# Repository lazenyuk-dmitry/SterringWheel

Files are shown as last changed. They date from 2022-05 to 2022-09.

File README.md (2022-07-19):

# Самодельный игровой руль с обратной связью

Это мой проект для личного использования. Здесь только чертежи проекта. Я использовал для чертежей **[FreeCAD](https://wiki.freecadweb.org/)**, это бесплатное ПО, скачать его можно **[здесь](https://wiki.freecadweb.org/Download)**.

Я сделал руль в основном из фанеры и ЛДСП. Я использовал два мотора 775 с передаточным числом 1:10.

Электроника основана на Arduino leonardo.

Для прошивки я использовал проект **[AFFBWheel](https://github.com/vsulako/AFFBWheel)**. Автор проекта своевременно исправляет ошибки и дорабатывает прошивку, добавляет новый функционал.

*Если будет интерес к проекту то я буду дополнять описание и чертежи. О своей заинтересованности или по каким то вопросам можете писать в **[Discussions](https://github.com/lazenyuk-dmitry/SterringWheel/discussions)**.*

Цвета в проекте:

* chipboard - ЛДСП.
* plywood - фанера.

## Описание файлов проекта

* `assets` - содержит импортированные модели.
* `images` - картинки проекта.
* `pdf` - PDF файлы модели.
* `Base.FCStd` - модель базы.
* `PaddleShifter.FCStd` - модель подрулевых лепестков.
* `PaddleShifter-v2.FCStd` - подрулевые лепестки 2 версия.
* `Pedals.FCStd` - модель педалей.
* `Wheel.FCStd` - модель руля.

В программе *FreeCAD* есть справа панель. В ней ищите папку чертежи.
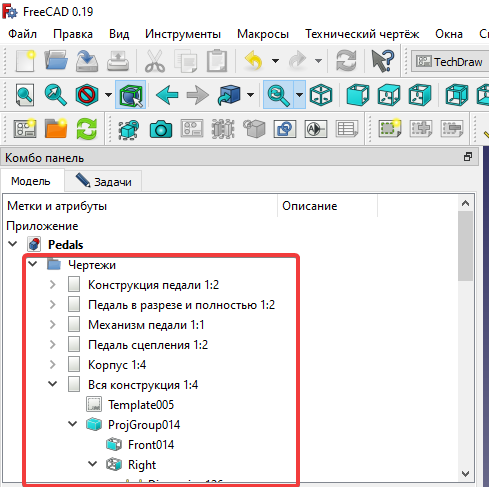
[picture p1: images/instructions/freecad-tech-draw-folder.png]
tech-draw-folder


## Немного фотографий

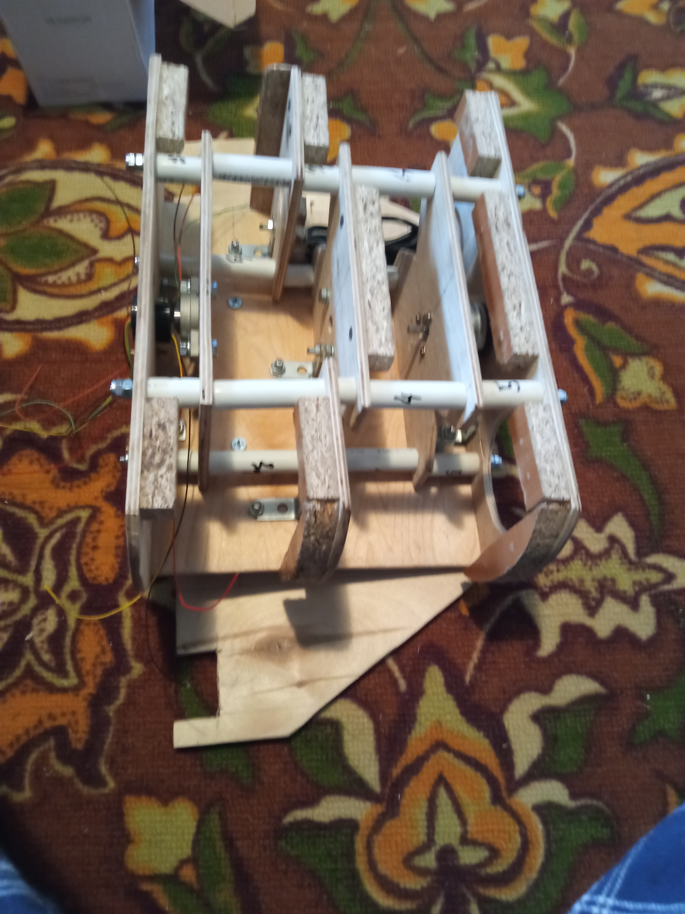
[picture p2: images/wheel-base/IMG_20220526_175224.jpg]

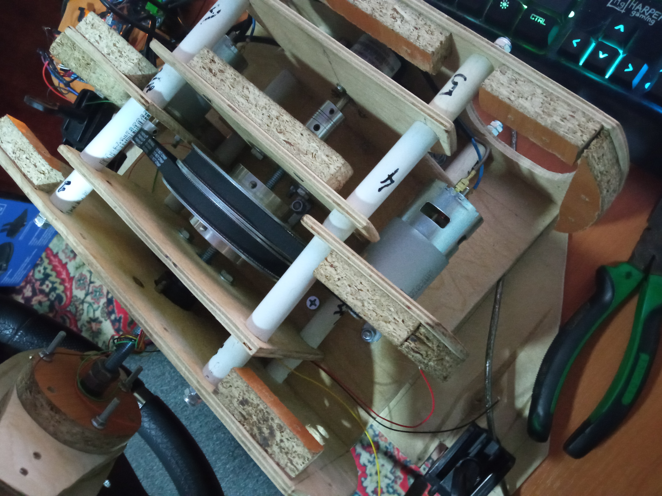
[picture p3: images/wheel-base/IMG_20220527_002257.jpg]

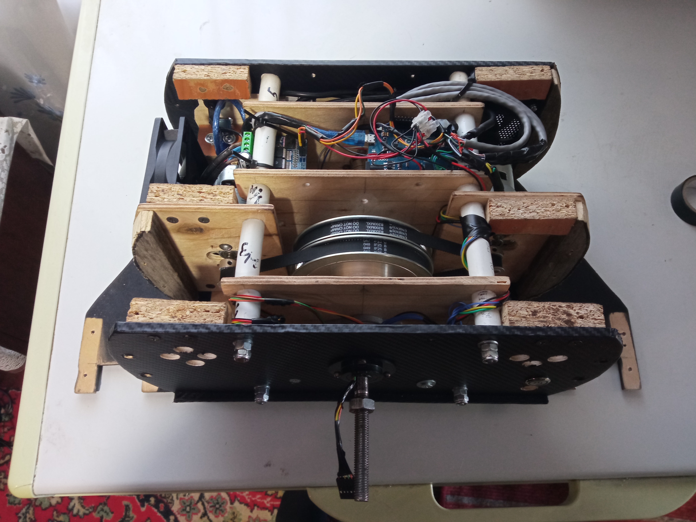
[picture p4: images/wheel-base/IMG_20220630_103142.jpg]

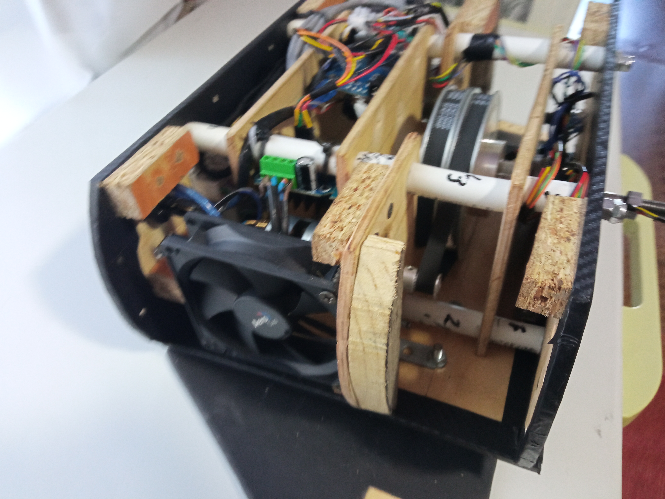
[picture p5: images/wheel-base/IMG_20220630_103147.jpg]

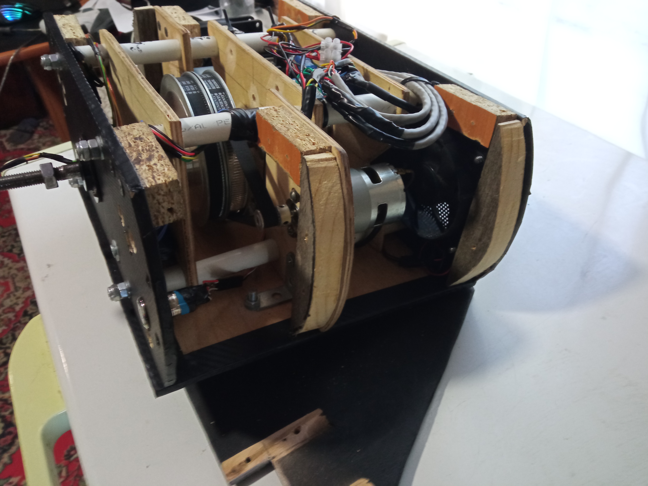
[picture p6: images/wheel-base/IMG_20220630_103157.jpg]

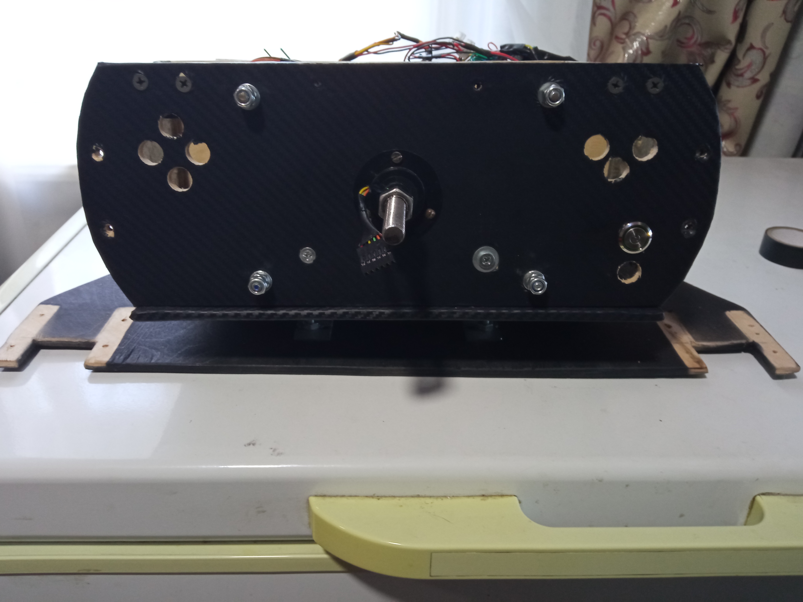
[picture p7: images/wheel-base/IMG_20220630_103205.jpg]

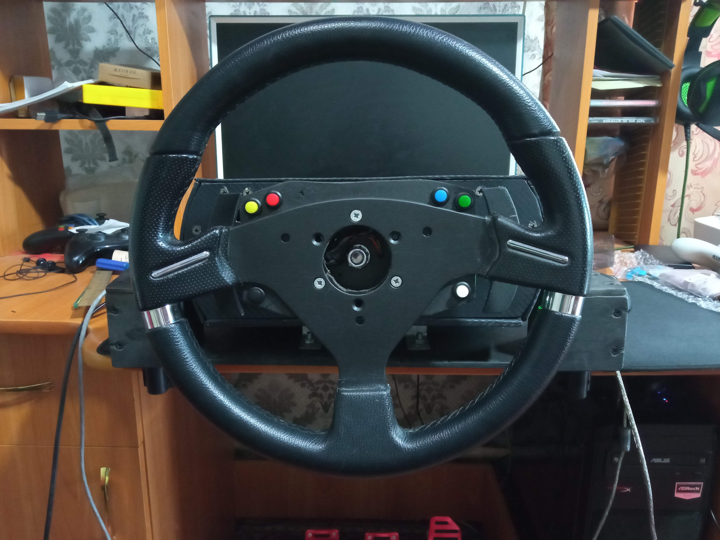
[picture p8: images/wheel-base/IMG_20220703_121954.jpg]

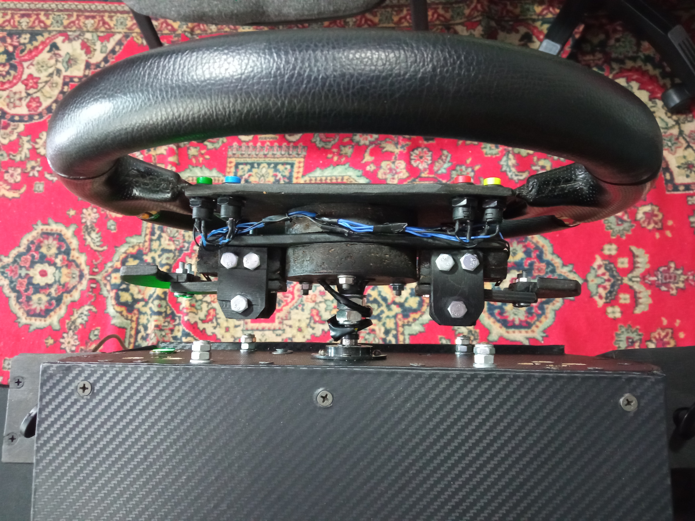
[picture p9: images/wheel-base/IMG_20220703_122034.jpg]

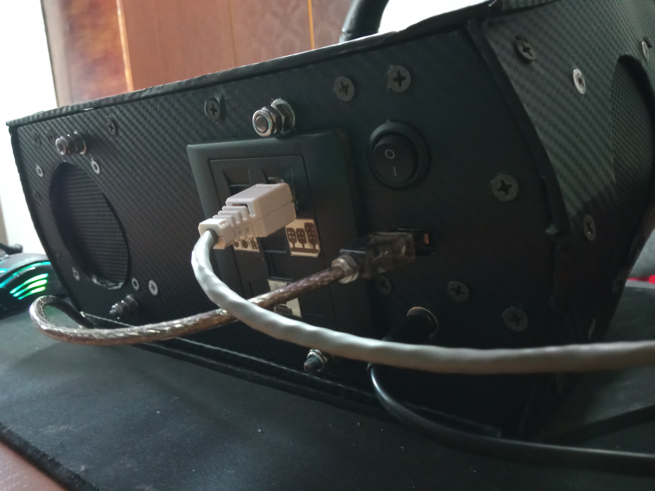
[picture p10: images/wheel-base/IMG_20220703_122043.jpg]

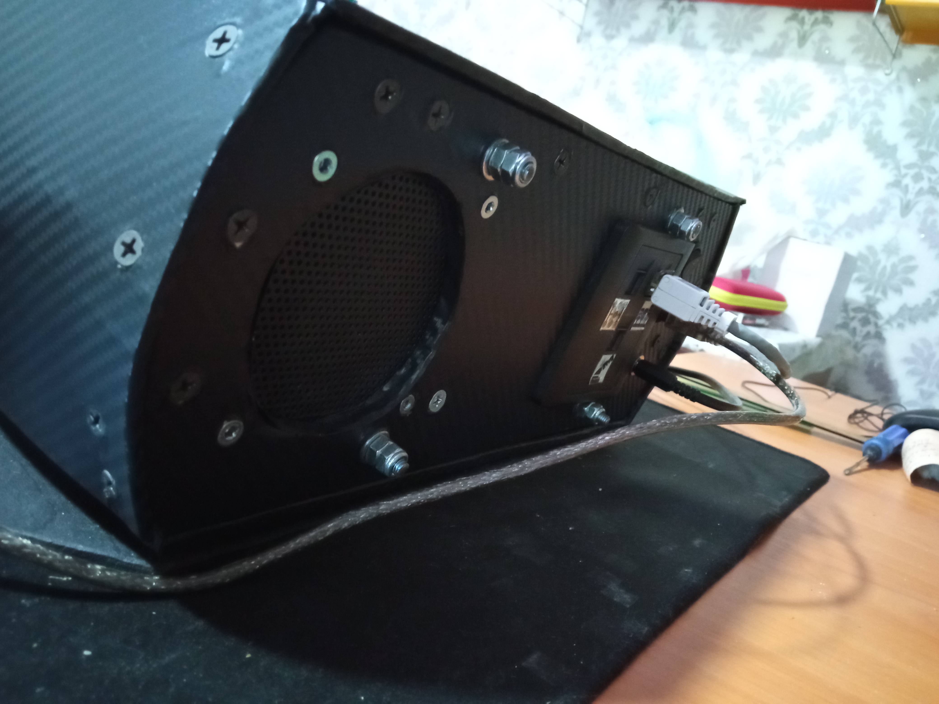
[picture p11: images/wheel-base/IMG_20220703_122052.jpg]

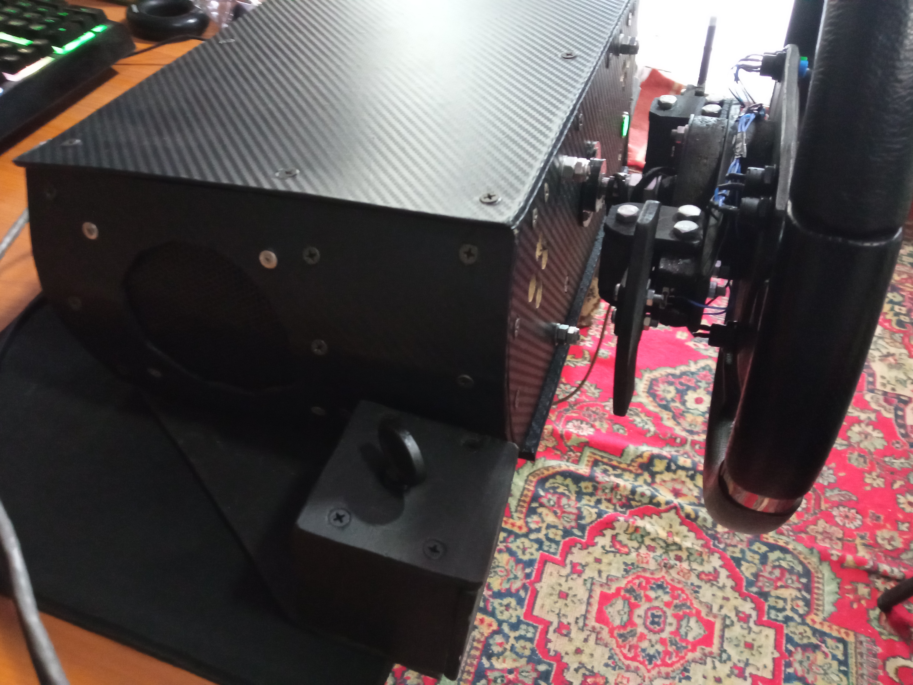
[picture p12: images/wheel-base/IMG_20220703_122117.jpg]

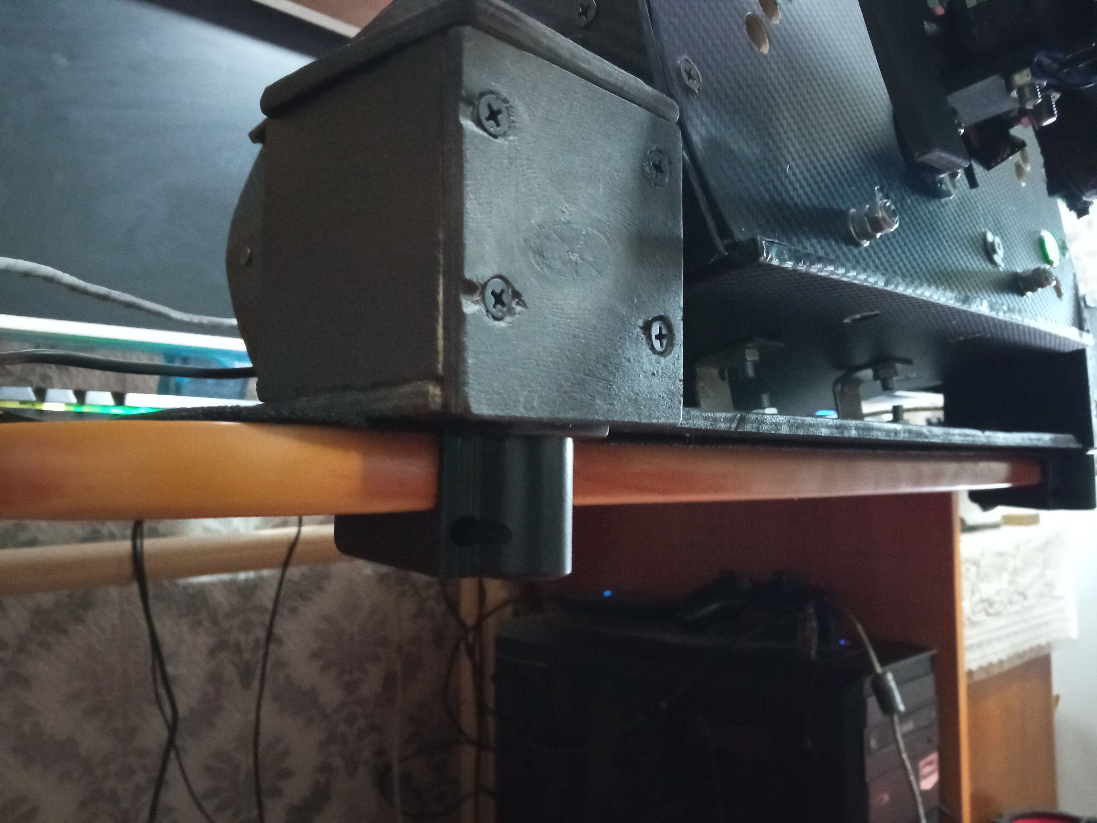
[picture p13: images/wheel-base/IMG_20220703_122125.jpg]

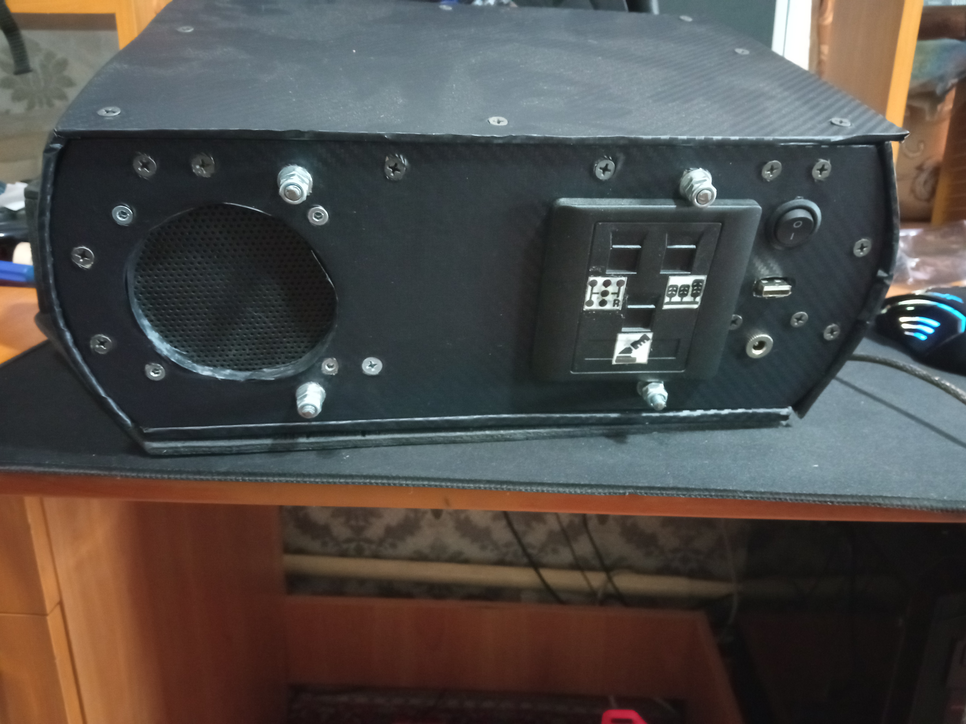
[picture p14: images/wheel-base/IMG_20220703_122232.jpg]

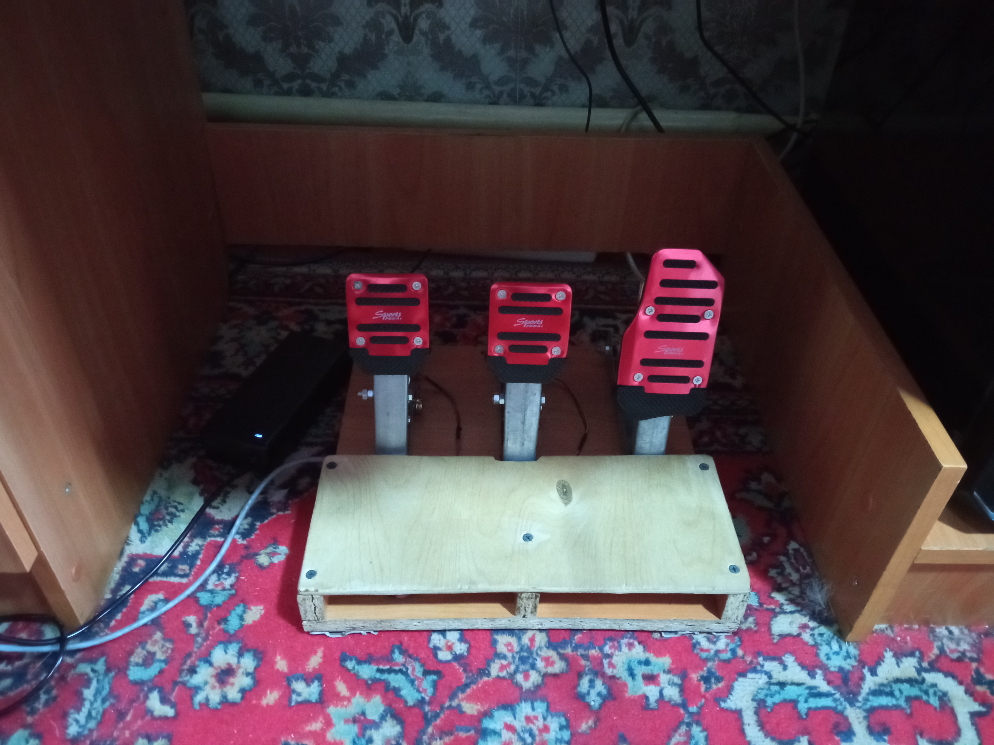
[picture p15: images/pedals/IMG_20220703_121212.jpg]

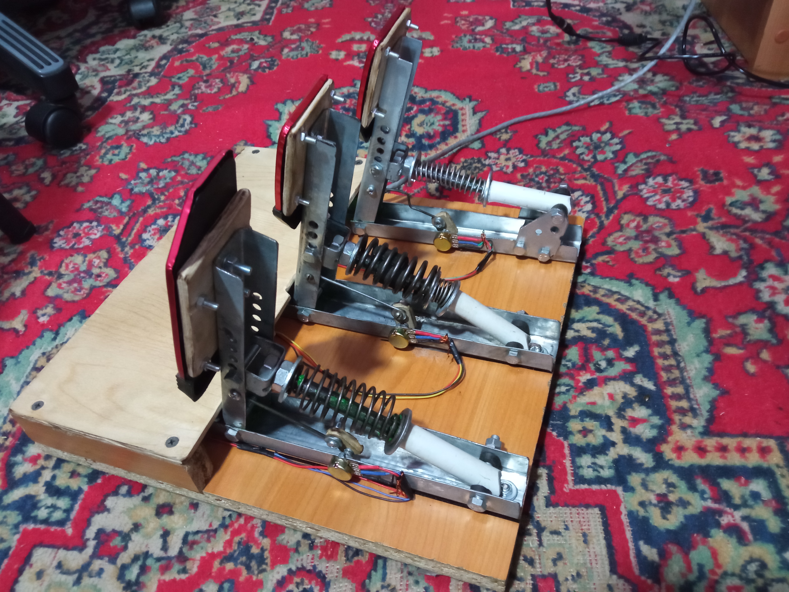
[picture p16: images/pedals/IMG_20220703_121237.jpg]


## Педали

Для педалей я использовал следующее:

* Профиль, вроде бы им усиливают пластиковые окна. Он мне достался бесплатно. <br>
 <br>
Профиль 30х20mm.
* Потенциометры на 10К.
* Проволока 1-2mm или спица от велосипеда.
* Фанера 6mm.
* ЛДСП 16mm.
* Накладки на педали я покупал **[здесь](https://aliexpress.ru/item/1005003505176644.html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)**. Но они мне не особо нравятся.
* Пружины использовал следующие:
  * Для педали газа **[Диаметр проволоки:2.0mm, Длинна:100mm (2Pcs), Наружныи диаметр:30mm](https://aliexpress.ru/item/4000436939383.html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)**. <br>
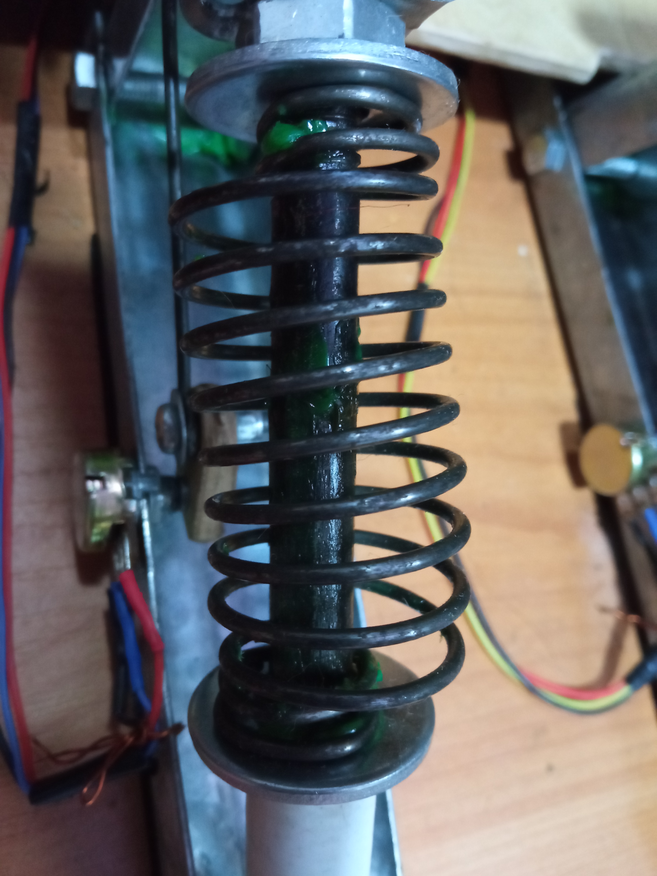
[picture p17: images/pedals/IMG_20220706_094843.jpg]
   <br>
  *Можно взять диаметр меньше так как пружина одевается на шток 10мм, возможно у вас будет другой*
  * Для педали сцепления **[1.5x18x305mm](https://aliexpress.ru/item/4001041195904.html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)**. <br>
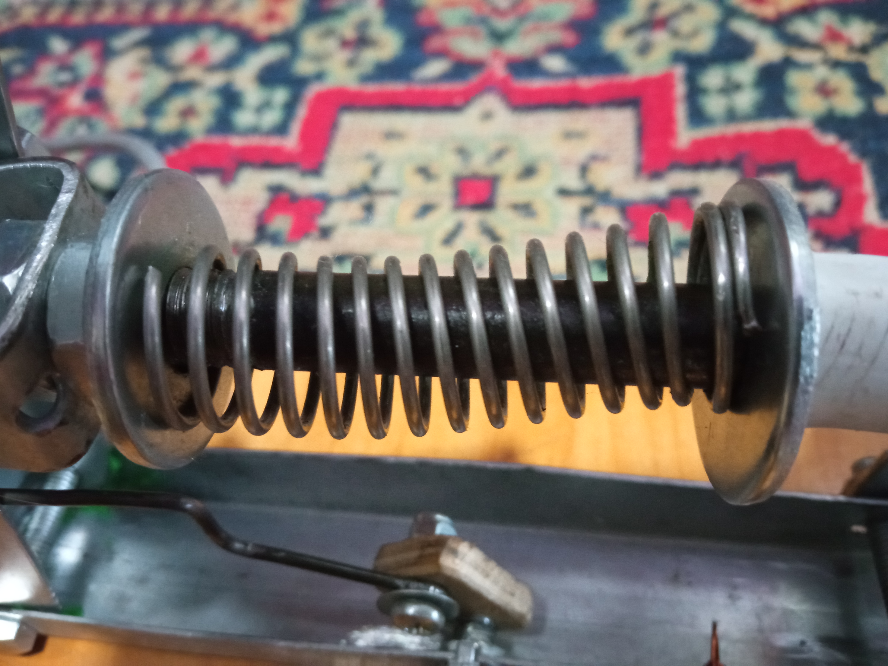
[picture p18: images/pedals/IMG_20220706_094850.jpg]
   <br>
  *Но мне кажется нужно потолще пружину ставить*.
  * На педаль тормоза я нашел пружину от клапанов *МТЗ*. Думаю можно подобрать от автомобиля или мотоцикла с клапанов. И добавил еще кусочек пружины 1.5мм <br>
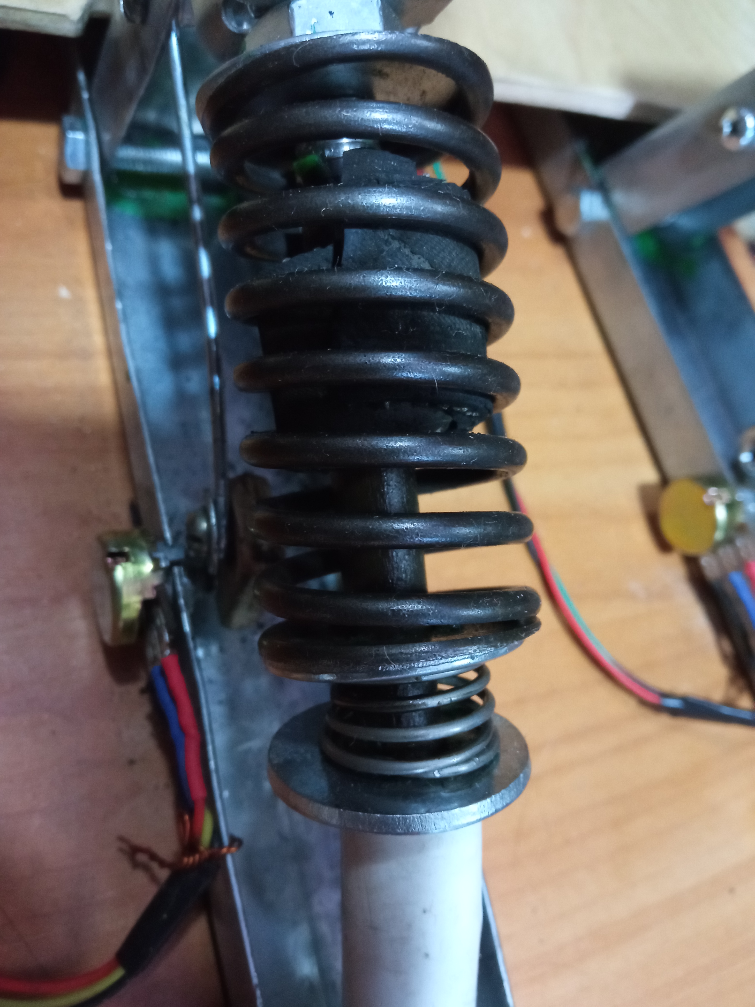
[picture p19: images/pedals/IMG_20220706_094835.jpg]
   <br>
  *У пружины большой внутренний диаметр поэтому я засунул во внутрь кусок шланга*.
* Труба металлопластик 16мм.
* Провода.
* Болты и гайки и шайбы M10, M6, M4.
* Шпилька для штока M10 а лучше прут 10мм и нарезать резьбу на краю. <br>
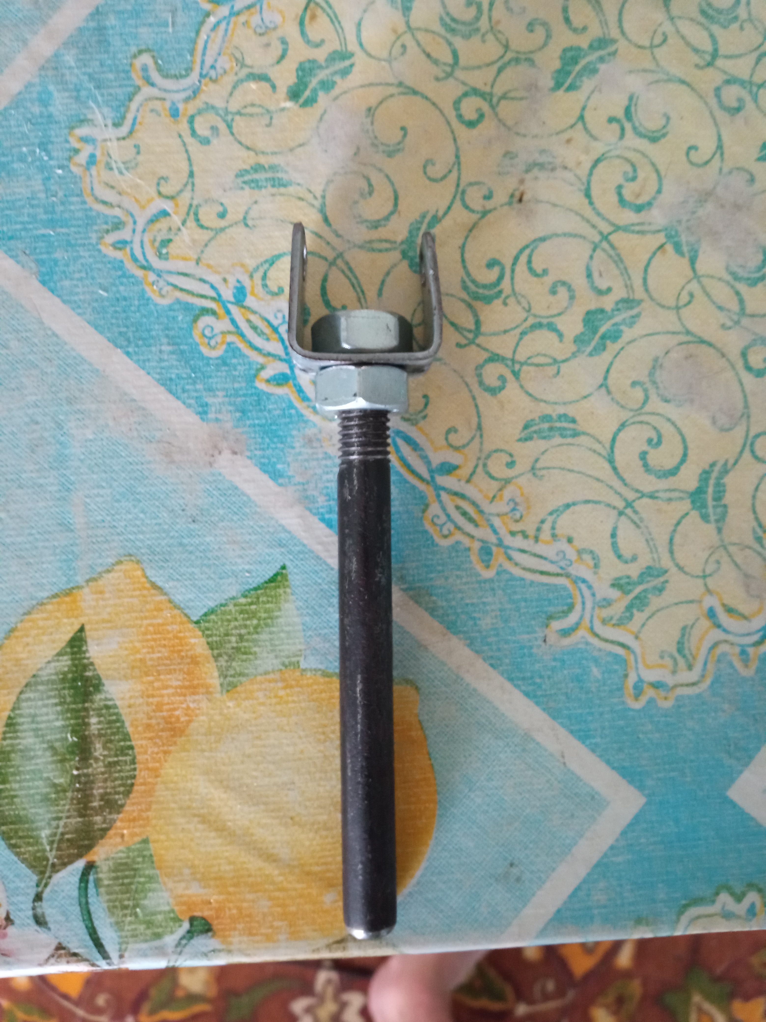
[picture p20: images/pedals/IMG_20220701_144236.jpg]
   <br>
  *Я не нашел нормальные шпильки. В магазине какая то острая резьба сильно и это мешает*. <br>
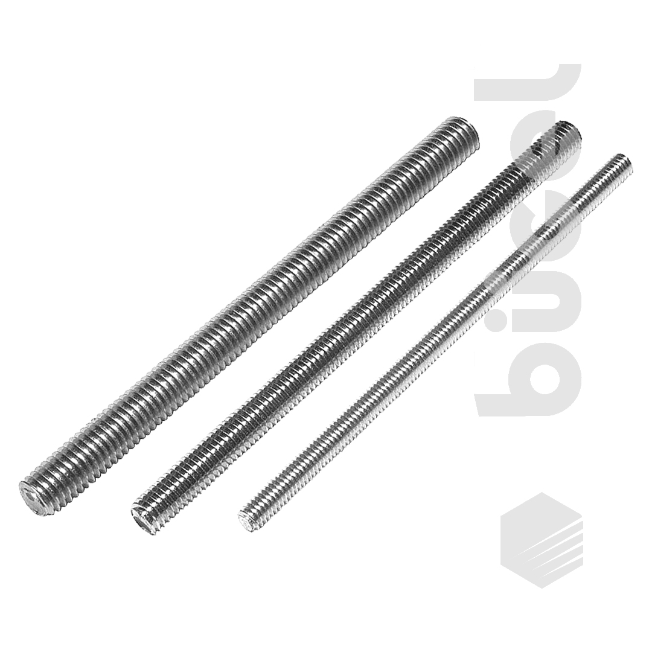
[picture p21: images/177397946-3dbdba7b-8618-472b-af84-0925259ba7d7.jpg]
   <br>
  Вот с такой резьбой шпильки найти будет нормально я думаю.
  <br>
  *Так что самое сложное - это сделать нормальный шток, чтобы он ходил во втулке и не терся резьбой. Можно конечно сделать и из фиговой шпильки, но будет не очень.*

### Конструкция педалей

Основное это нужно изготовить основу и рычаг из профиля.
main-construction
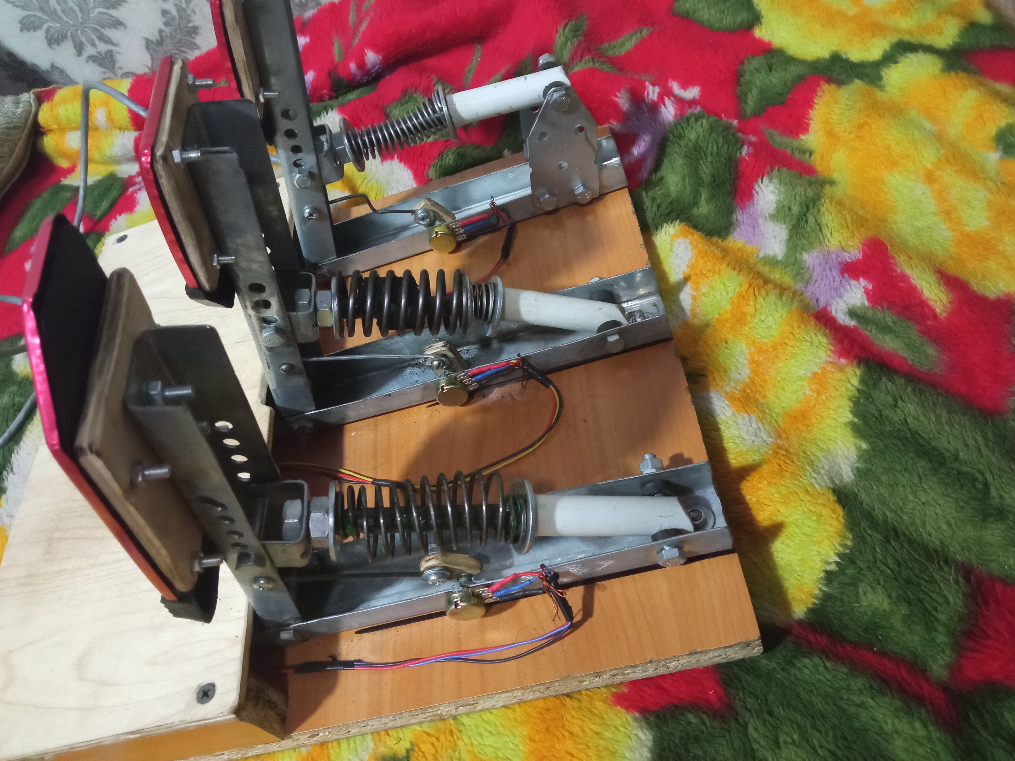
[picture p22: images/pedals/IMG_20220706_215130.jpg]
 <br>

А вот педаль в разрезе.
pedal-slice

*На фотографиях педаль сцепления отличается креплением втулки. Это я пробовал сделать сцепление с эффектом корзины, но пока что не получилось. Но так если выше поднять втулку мне кажется становится жестче педаль.*

Теперь нужно изготовить механизм педали. Шток, втулку и крепление к рычагу.
main-mechanism
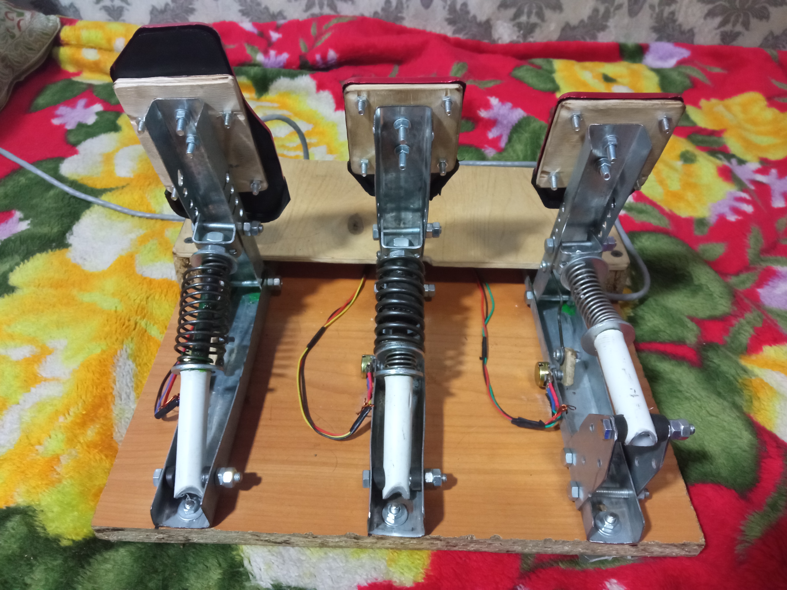
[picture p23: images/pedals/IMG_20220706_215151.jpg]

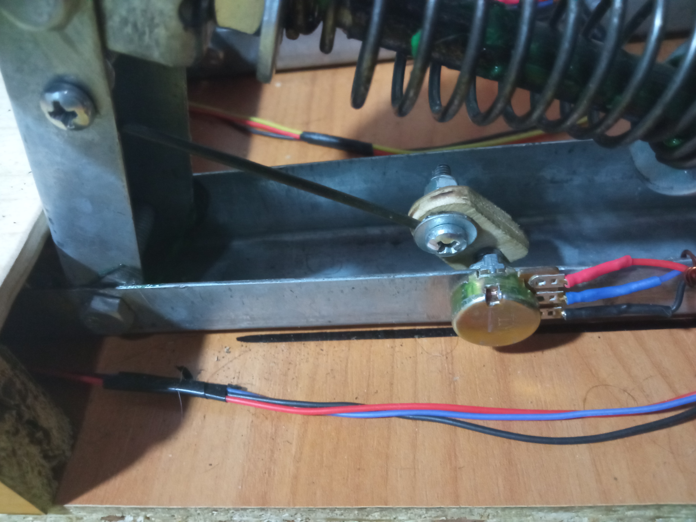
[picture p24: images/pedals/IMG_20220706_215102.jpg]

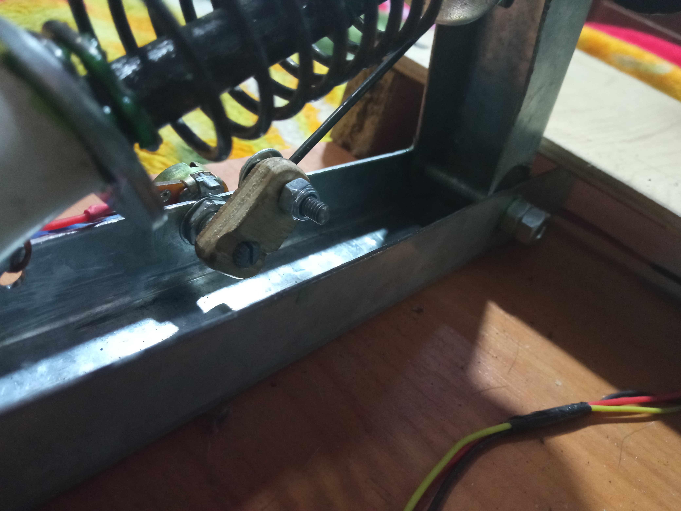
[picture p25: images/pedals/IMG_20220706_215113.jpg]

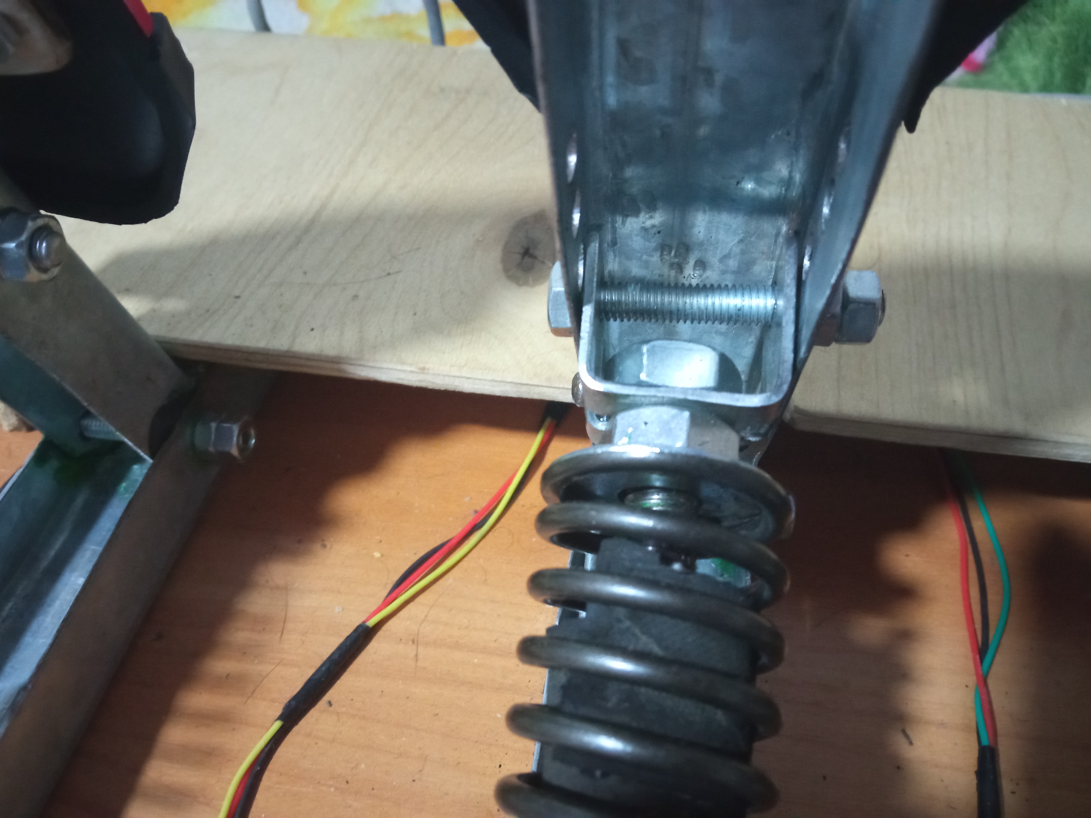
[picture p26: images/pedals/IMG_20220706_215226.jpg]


Втулку я немного закруглил и вставил кусочки шланга.
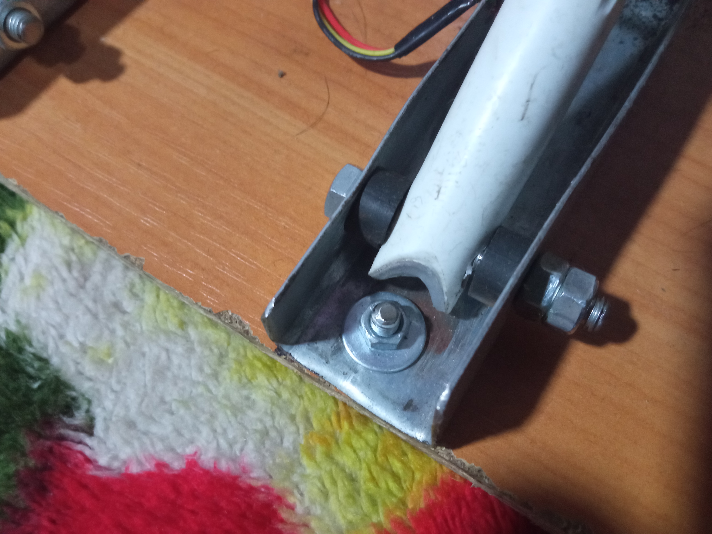
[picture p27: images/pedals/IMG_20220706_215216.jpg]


Есть чертеж такой педали сцепления с эффектом корзины. За прототип взял педали caravangoes. Но я еще не проверял эту идею. Пока только набросок.
clutch-pedal

Ну в принципе и все. Собираем педали. И делаем корпус.
box

Затем устанавливаем все на корпус.
all-proection

Накладки на педали можно сделать и из фанеры.
pedal-pad

На низ я прикрутил куски резины вырезанные из б/у автомобильного коврика.
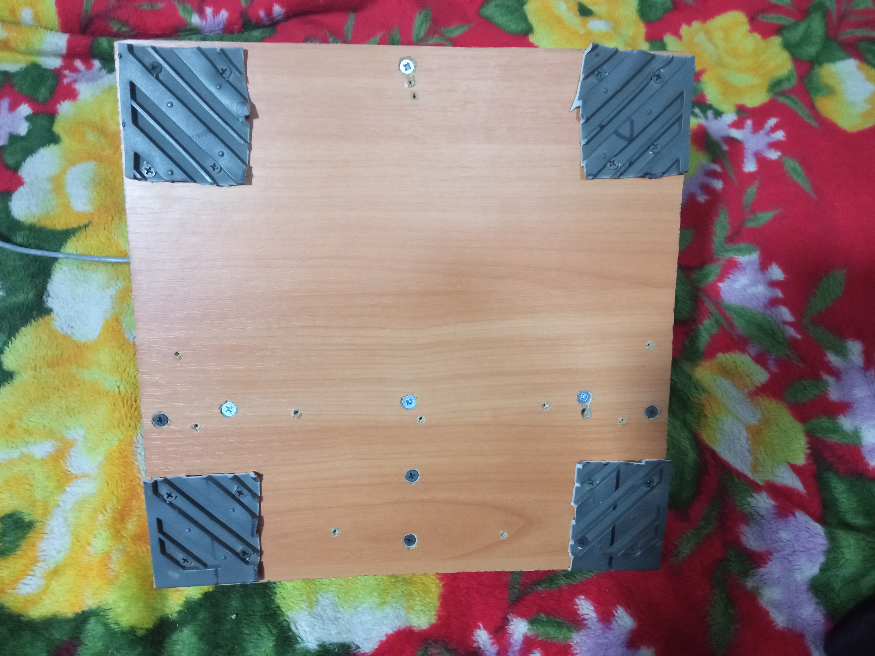
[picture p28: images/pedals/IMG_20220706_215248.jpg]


Вот собственно и вся конструкция педалей.

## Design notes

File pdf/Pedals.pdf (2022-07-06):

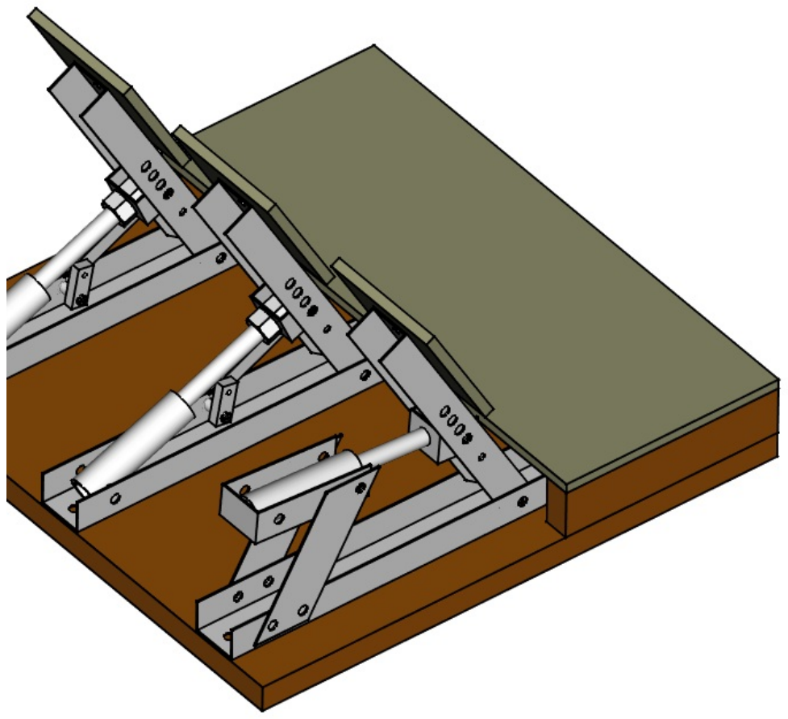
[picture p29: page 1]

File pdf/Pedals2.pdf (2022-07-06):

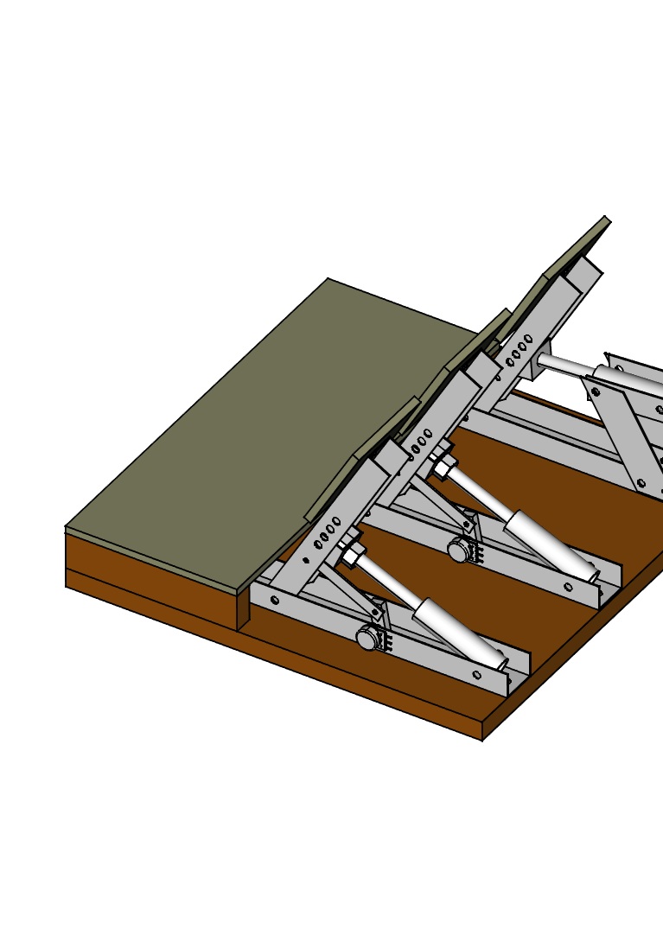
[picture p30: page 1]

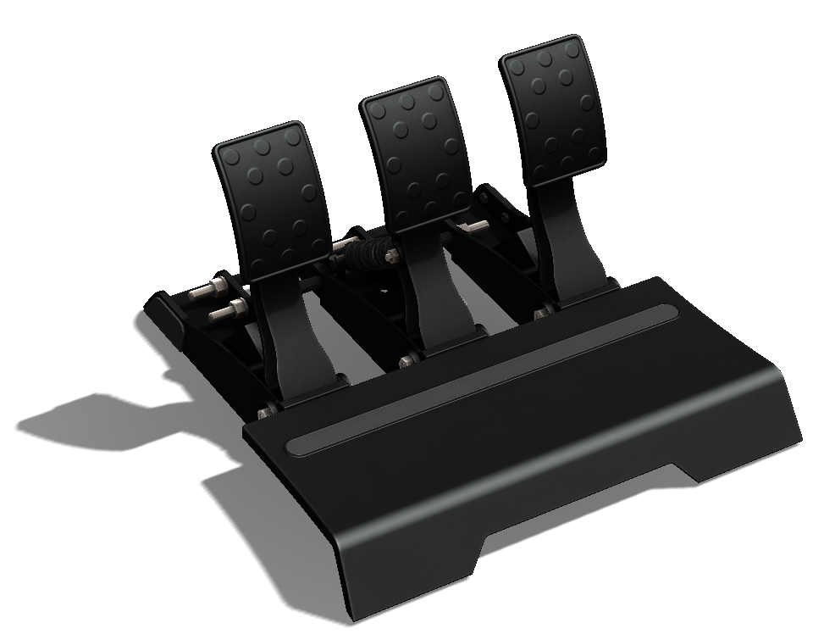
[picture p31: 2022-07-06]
assets/fanatec-csl-elite-pedals-1.snapshot.8/Frt.png

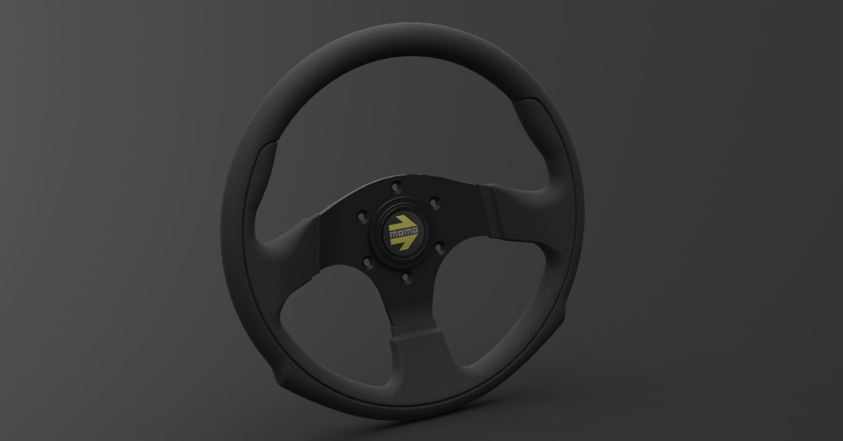
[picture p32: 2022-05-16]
assets/momo-team-300-steering-wheel-1.snapshot.1/momo team 300 steering wheel 1.JPG

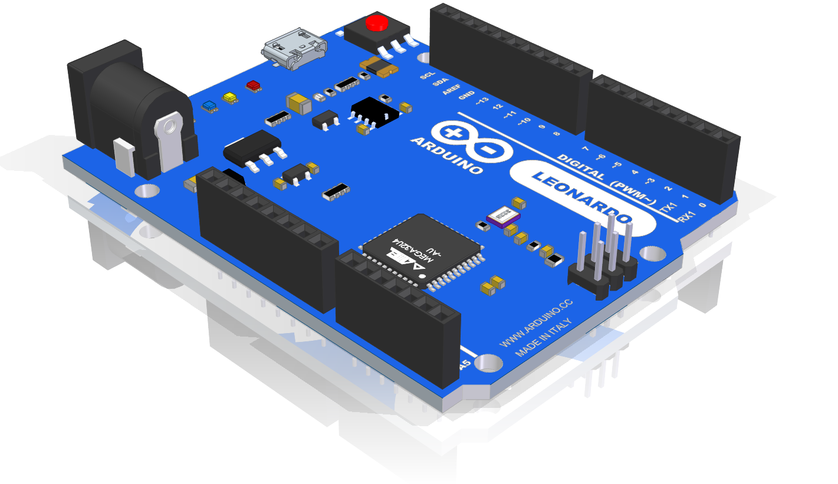
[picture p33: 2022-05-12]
assets/arduino-leonardo-4.snapshot.55/Arduion Leonardo.PNG

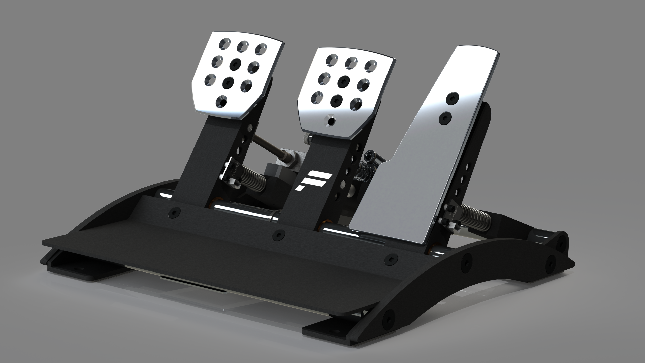
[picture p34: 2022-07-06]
assets/fanatec-csp-v2-1.snapshot.5/Renderings/004 gris.png

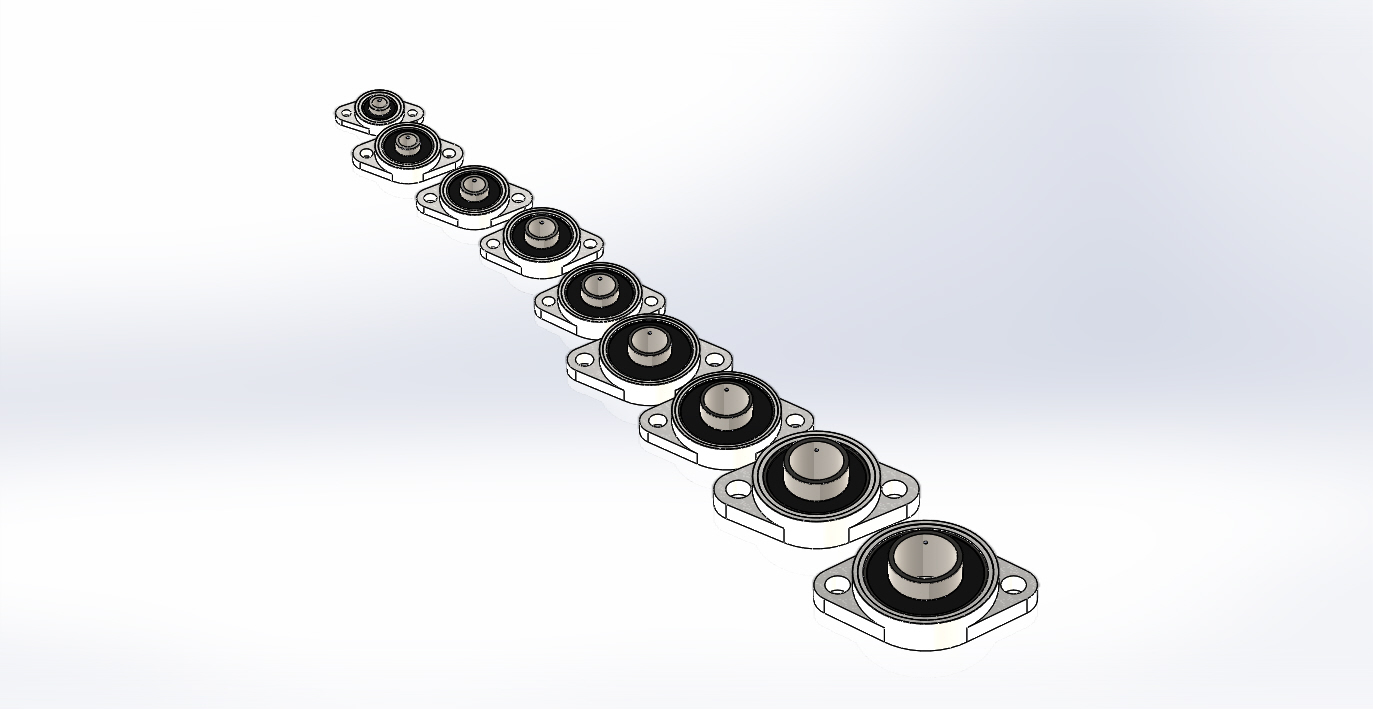
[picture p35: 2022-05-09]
assets/kfl-bearing-or-block-flange-ball-bearing-1.snapshot.10/Bearing KFL series/Rendering/KFL series with 8 items.JPG

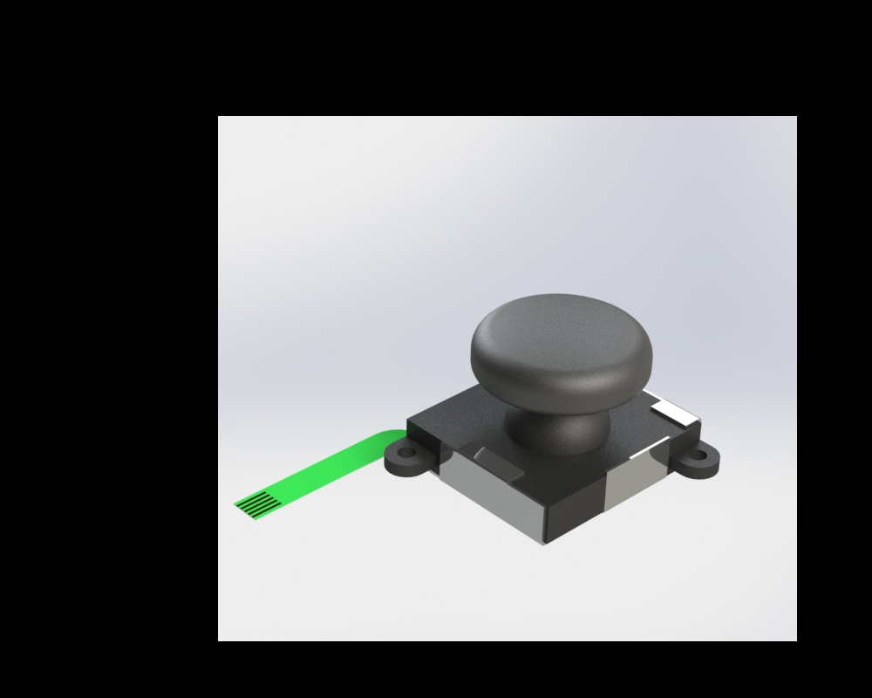
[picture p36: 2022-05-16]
assets/nintendo-switch-joystick-1.snapshot.1/Switch Joystick.JPG

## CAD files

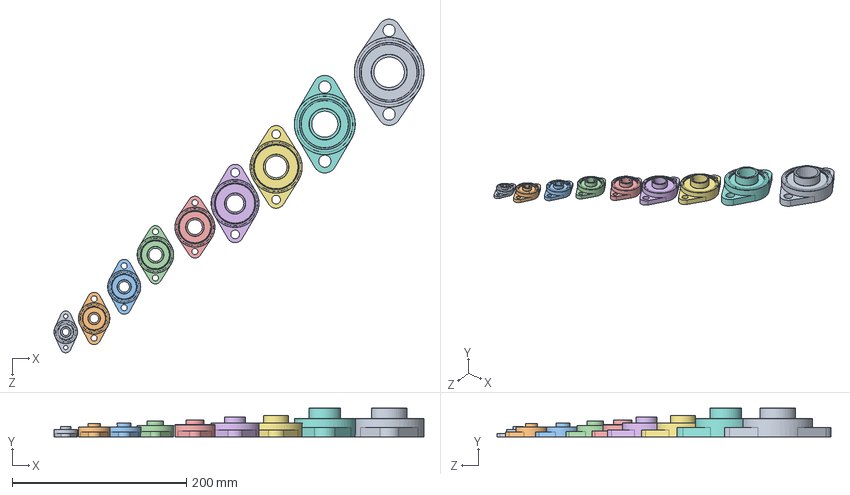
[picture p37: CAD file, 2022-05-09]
assets/kfl-bearing-or-block-flange-ball-bearing-1.snapshot.10/Bearing KFL series/all items view.SLDASM
424.5 x 33.0 x 382.8 mm
KFL08 block flange ball bearing 08 diameter shaft
KFL000 block flange ball bearing 10mm diameter shaft
KFL001 block flange ball bearing 12 diameter shaft
KFL002 block flange ball bearing 15 diameter shaft
KFL003 block flange ball bearing 17 diameter shaft
KFL004 block flange ball bearing 20 diameter shaft
KFL005 block flange ball bearing 25 diameter shaft
KFL006 block flange ball bearing 30 diameter shaft
KFL007 block flange ball bearing 35 diameter shaft

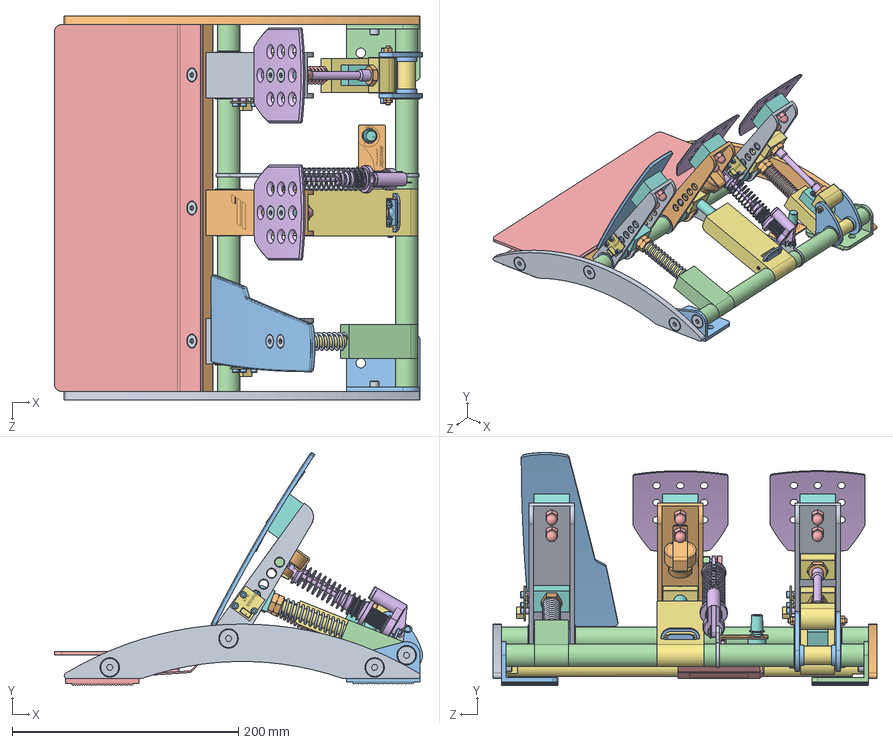
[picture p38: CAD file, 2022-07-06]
assets/fanatec-csp-v2-1.snapshot.5/00 - Pedalier CSP V2.SLDASM
325.1 x 205.9 x 339.0 mm
01 - Pied
02 - Pied SYM
03 - Equerre fixation sol
04 - Equerre fixation sol SYM
05 - Equerre fixation sol 2
06 - Equerre fixation sol 2 SYM
07 - Axe court x 2
08 - Axe long
09 - Levier pedales A-E x 2
10 - Levier pedales F
11 - Palier bronze x 8
12 - Pivot suspension
13 - Ecrou suspension
14 - Amortisseur
15 - Pivot levier x 4
16 - Coulisseau frein
17 - Axe nu x 2
18 - Vibreur
19 - Axe capteur x 2
20 - Coulisseau embrayage
21 - Ressort embrayage
22 - Biellette embrayage
24 - Guide coulisseau taraudé
25 - Tampon embrayage
26 - Axe 12mm
27 - Axe 8mm
28 - Pivot renvoi x 2
29 - Entretoise x 10
30 - Pousseur mousse
31 - Mousse loadcell
32 - Guide coulisseau frein
33 - Entretoise pedale x 3
34 - Patte suspension
35 - Patte potentiometre
36 - Loadcell
23 - Guide coulisseau simple
37 - Repose pied
38 - Pedale F-E x 2
39 - Coulisseau accelerateur
40 - Pivot levier carre
41 - Ressort accelerateur
43 - Barre transversale
44 - Pedale A
45 - Goupille
46 - Support controleur
47 - Entretoise capteur x 9
48 - Capteur hall x 3
49 - Potentiometre
Vis FHc x 19
Ecrou Hm x 11
Vis CHc x 10
Vis Hc à bout plat x 2
Ecrou borgne x 6

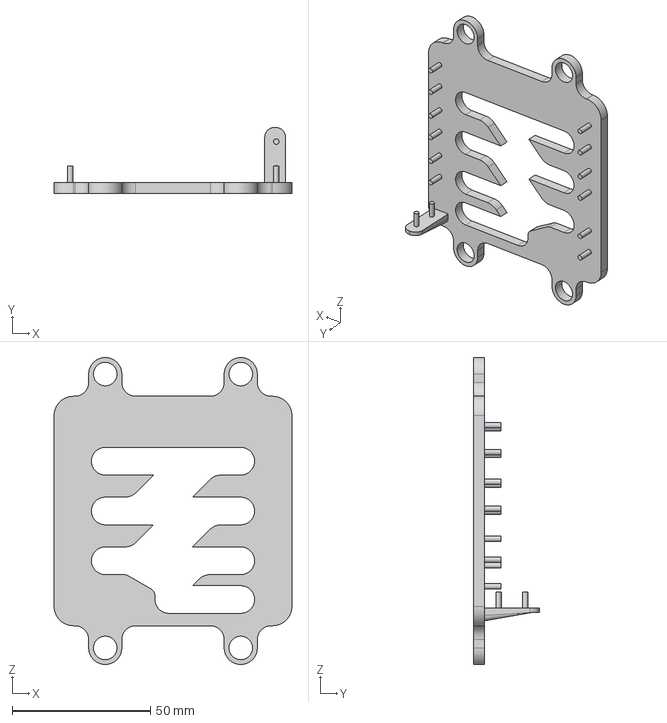
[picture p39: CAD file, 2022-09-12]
assets/6-speed-lower-plate-for-noctiluxx-s-h-shifter-1.snapshot.2/Lower Plate.step
86.0 x 23.9 x 111.0 mm

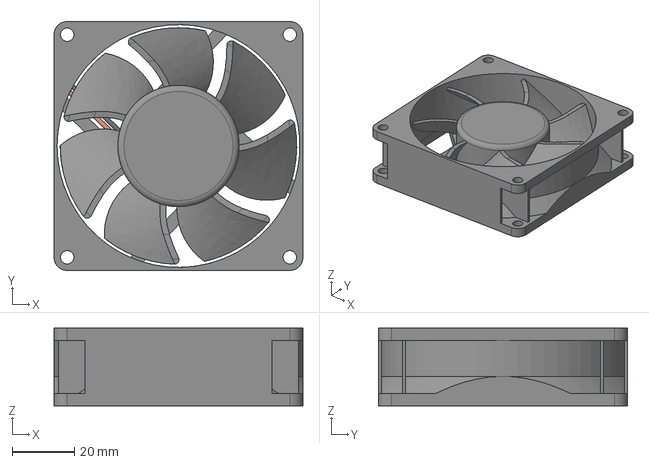
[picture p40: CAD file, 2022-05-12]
assets/80mm-brushless-fan-sunon-kd1208ptb1-2.snapshot.12/80mm brushless fan (SUNON KD1208PTB1).step
80.0 x 80.0 x 25.0 mm

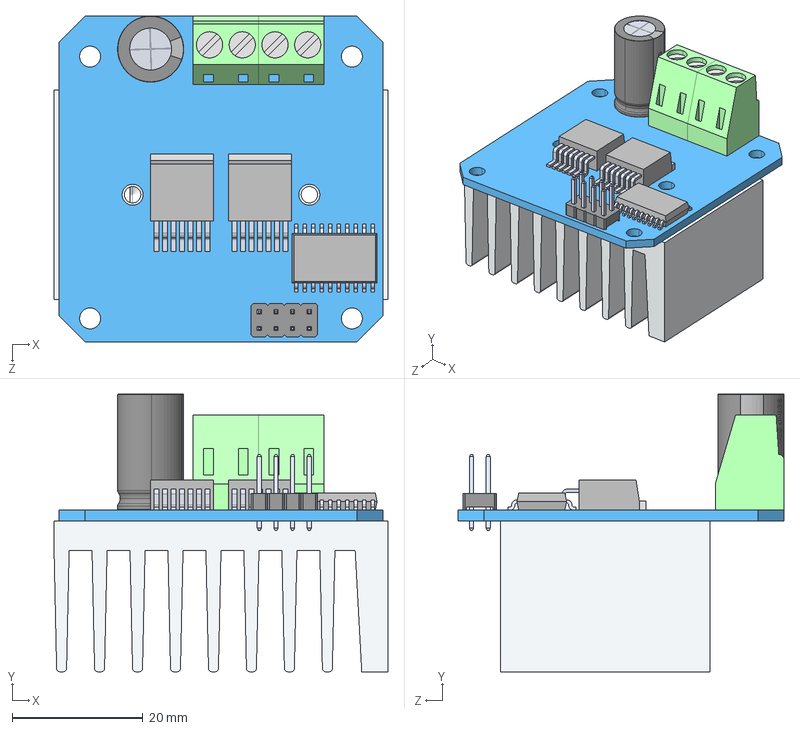
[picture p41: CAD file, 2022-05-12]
assets/bts7960-43a-high-power-h-bridge-module-1.snapshot.10/BTS7960 43A HIGH POWER H BRIDGE MODULE.STEP
51.0 x 42.4 x 49.8 mm
PCB, BTS7960 43A HIGH POWER H BRIDGE MODULE
HEATSINK, BTS7960 43A HIGH POWER H BRIDGE MODULE
ALUMINUM ELECTROLYTIC CAPACITOR, 330 uF, BTS7960 43A HIGH POWER H BRIDGE MODULE
BTN7960 IC, BTS7960 43A HIGH POWER H BRIDGE MODULE x 2
NXP 74HC244D, BUFFER AND LINE DRIVER, BTS7960 43A HIGH POWER H BRIDGE MODULE
8 PIN HEADER, IC, BTS7960 43A HIGH POWER H BRIDGE MODULE
EUROSTYLE TERMINAL BLOCK 2 POS 5.0 MM RA PLUG, BTS7960 43A HIGH POWER H BRIDGE MODULE x 2

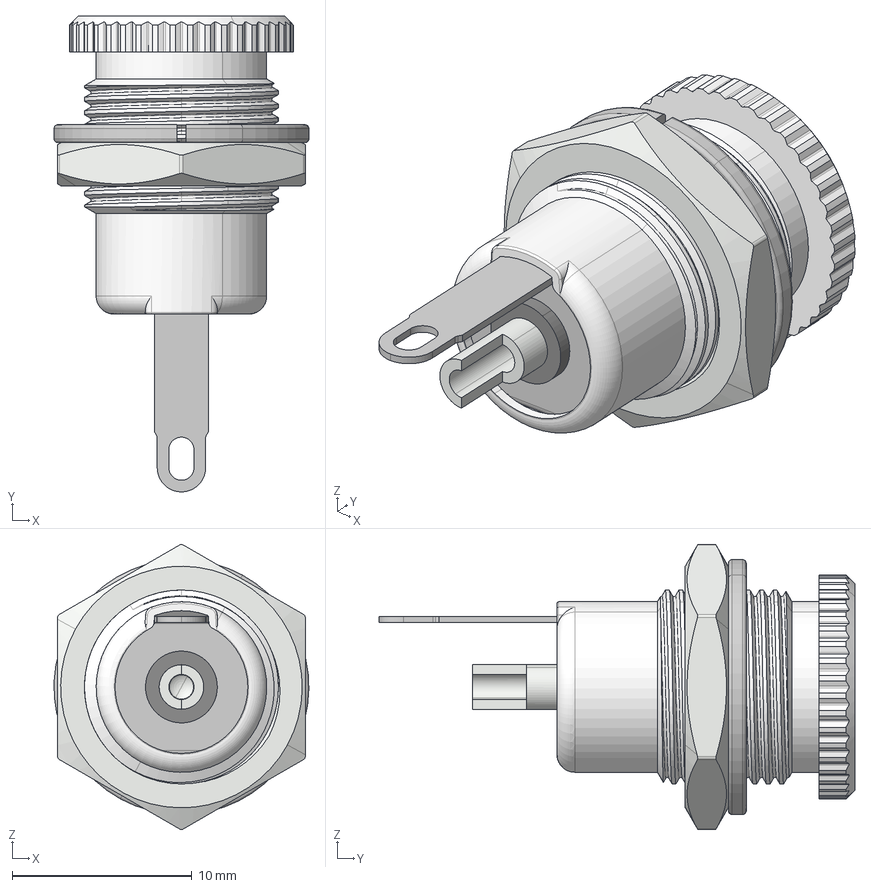
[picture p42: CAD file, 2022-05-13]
assets/connector-5-5x2-5-dc00990-b-1.snapshot.1/Connector_5,5-2,5_DC00990-B.stp
14.2 x 26.5 x 15.9 mm

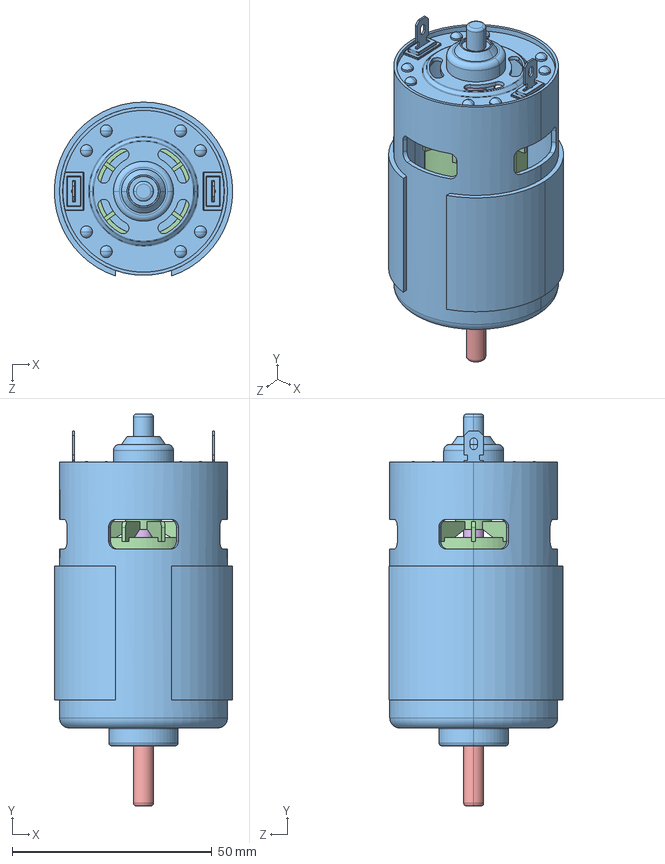
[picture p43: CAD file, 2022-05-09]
assets/dc-motor-rs-775-12v-12000-rpm-1.snapshot.1/Motor - RS-775.STEP
44.6 x 98.0 x 43.5 mm

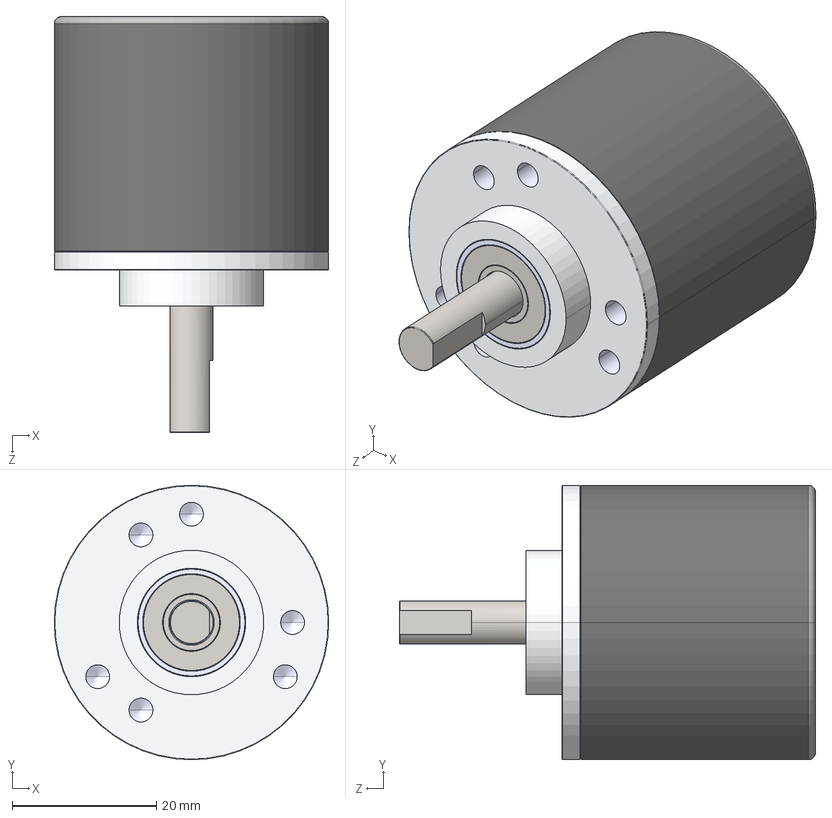
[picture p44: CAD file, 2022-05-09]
assets/encoder-36.snapshot.2/Encoder hn3806.STEP
38.0 x 38.0 x 57.6 mm

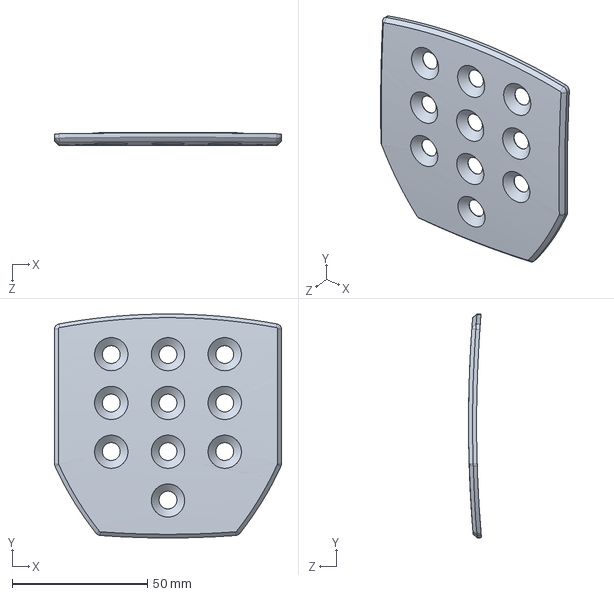
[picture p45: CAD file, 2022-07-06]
assets/fanatec-csp-v2-1.snapshot.5/38 - Pedale F-E.SLDPRT
84.0 x 82.9 x 4.80 mm

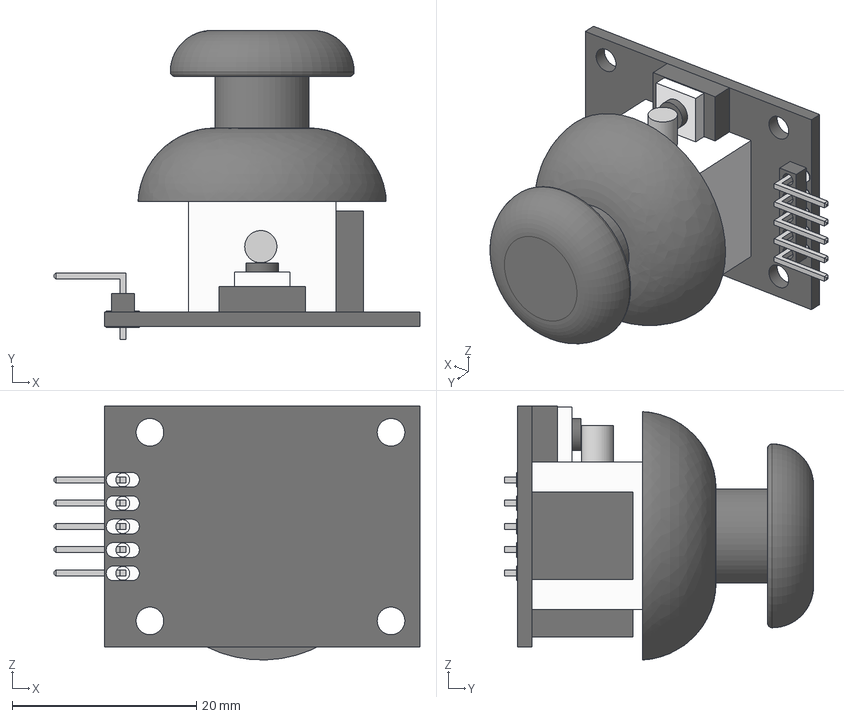
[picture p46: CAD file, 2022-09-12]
assets/joy-stick-4.snapshot.1/joy_stick_a2/joy_stick_2a.step
39.8 x 33.6 x 27.6 mm

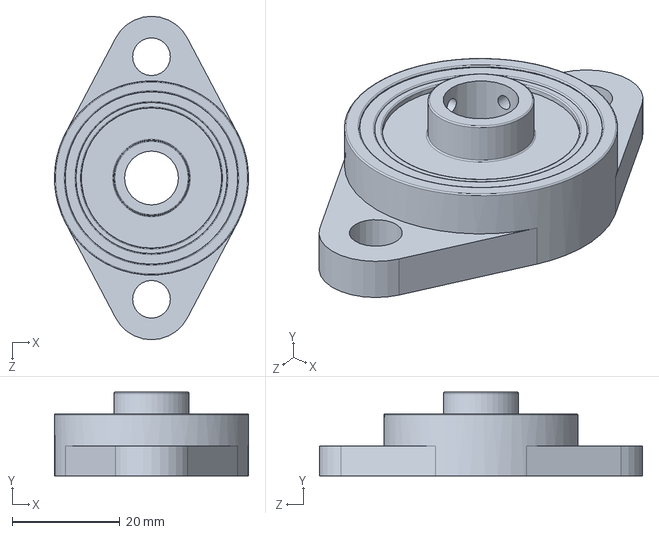
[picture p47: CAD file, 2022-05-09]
assets/kfl-bearing-or-block-flange-ball-bearing-1.snapshot.10/Bearing KFL series/KFL000 block flange ball bearing 10mm diameter shaft.SLDPRT
36.0 x 15.5 x 60.0 mm

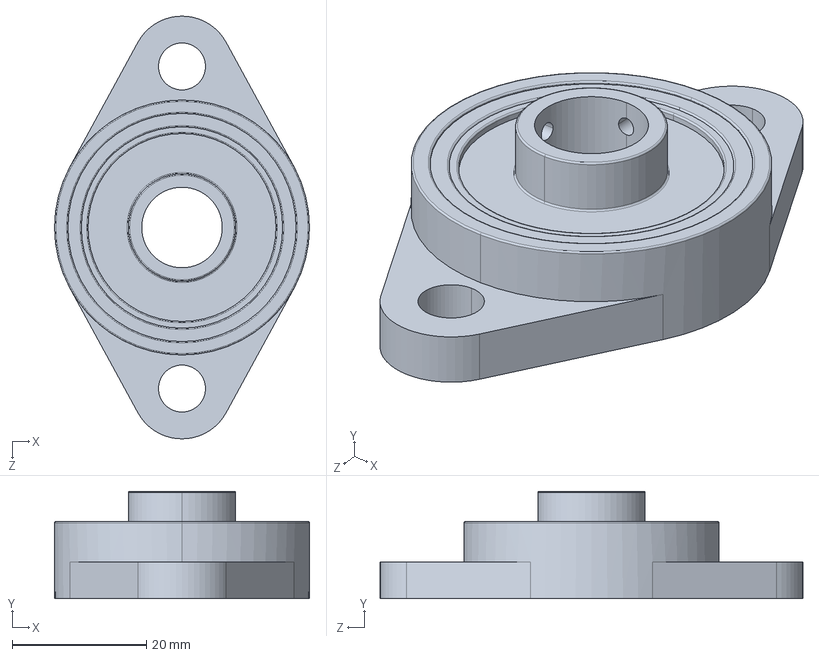
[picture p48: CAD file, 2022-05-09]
assets/kfl-bearing-or-block-flange-ball-bearing-1.snapshot.10/step files/KFL001 block flange ball bearing 12 diameter shaft.STEP
38.0 x 16.0 x 63.0 mm

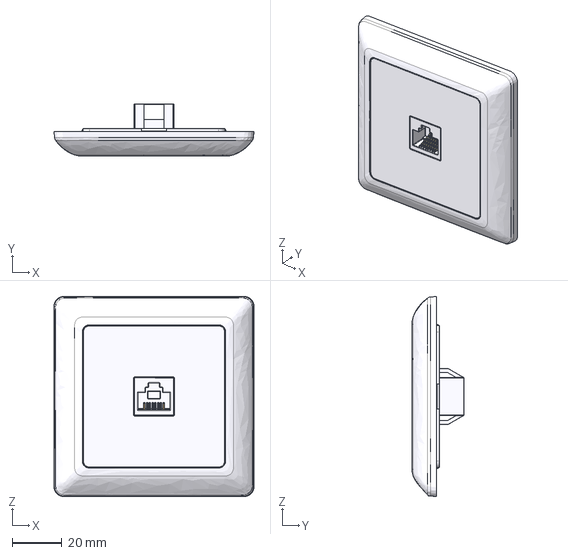
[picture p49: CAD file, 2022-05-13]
assets/lan-rj-45-socket-1.snapshot.3/lan RJ 45 socket.stp
80.5 x 21.1 x 80.5 mm

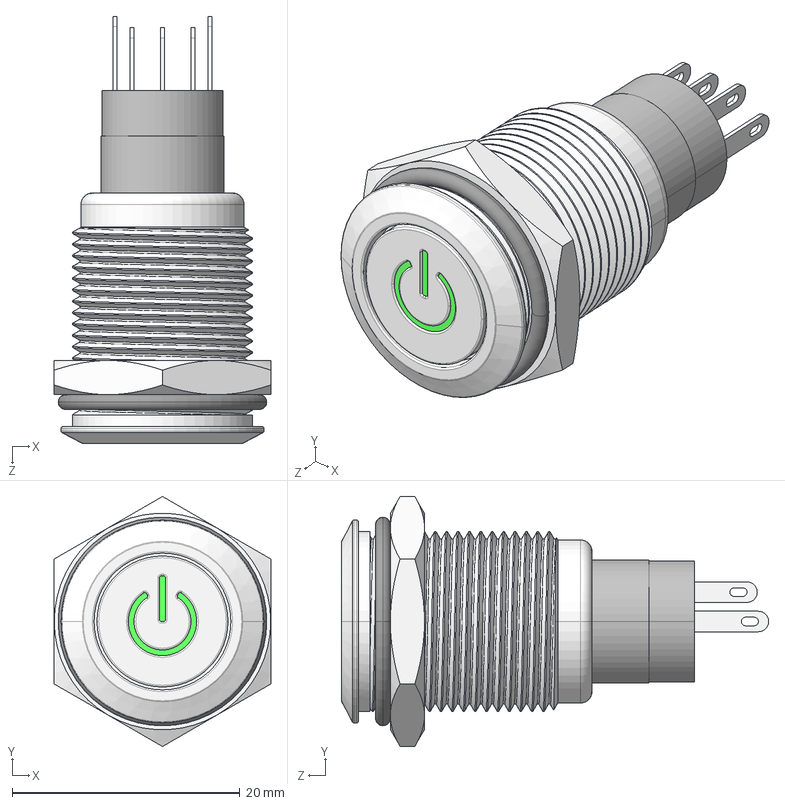
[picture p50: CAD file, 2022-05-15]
assets/metal-led-illuminated-latching-16mm-power-push-button-on-off-switch-12v-1.snapshot.2/Metal LED Illuminated Latching 16mm Power Push Button ON-OFF Switch 12V.STEP
19.0 x 21.9 x 37.5 mm

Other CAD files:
assets/metal-steering-wheel-1.snapshot.2/vairas.STEP
assets/micro-switch-with-lever-1.snapshot.3/Micro Switch with Lever closed.stp
assets/momentary-push-button-switch-sgi-r13-502-1.snapshot.1/momentary_push_button_sw/push_button_SGI_R13-502.STEP
assets/nintendo-switch-joystick-1.snapshot.1/Sheet.SLDPRT
HandBrake.FCStd
PaddleShifter-v2.FCStd
PaddleShifter.FCStd
Pedals.FCStd
SterringWheel-Base.FCStd
assets/bts7960-43a-high-power-h-bridge-module-1.snapshot.10/8 PIN HEADER, IC, BTS7960 43A HIGH POWER H BRIDGE MODULE.SLDPRT
assets/bts7960-43a-high-power-h-bridge-module-1.snapshot.10/ALUMINUM ELECTROLYTIC CAPACITOR, 330 uF, BTS7960 43A HIGH POWER H BRIDGE MODULE.SLDPRT
assets/bts7960-43a-high-power-h-bridge-module-1.snapshot.10/BTN7960 IC, BTS7960 43A HIGH POWER H BRIDGE MODULE.SLDPRT
assets/bts7960-43a-high-power-h-bridge-module-1.snapshot.10/BTS7960 43A HIGH POWER H BRIDGE MODULE.SLDASM
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

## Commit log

2022-05-09 Add files.
    [Encoder hn3806.SLDPRT, Encoder hn3806.STEP, KFL000 block flange ball bearing 10mm diameter shaft.SLDPRT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]
2022-05-09 Add 2 motors.
    [SterringWheel-Base.FCStd]
2022-05-10 Add encoder.
    [SterringWheel-Base.FCStd]
2022-05-11 Remade structure with parts.
    [SterringWheel-Base.FCStd]
2022-05-12 Complete main construction.
    [SterringWheel-Base.FCStd]
2022-05-12 Add 2 fans, arduino and bts7960
    [8 PIN HEADER, IC, BTS7960 43A HIGH POWER H BRIDGE MODULE.SLDPRT, 80mm brushless fan (SUNON KD1208PTB1).step, ALUMINUM ELECTROLYTIC CAPACITOR, 330 uF, BTS7960 4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]
2022-05-13 Marked the conclusions on the rear panel.
    [Connector_5,5-2,5_DC00990-B.stp, Rocker Switch - Arcolectric R13 112C AAA.stl, Rocker Switch - Arcolectric R13 112C AAA.stp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]
2022-05-13 Added mounts for boards and fans and side walls.
2022-05-15 Add buttons on front panel.
    [Metal LED Illuminated Latching 16mm Power Push Button ON-OFF Switch 12V.IGS, Metal LED Illuminated Latching 16mm Power Push Button ON-OFF Switch 12V.SLDPRT, Me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]
2022-05-16 Improved positions if the buttons.
2022-05-16 Add wheel template
    [Sheet.SLDPRT, Switch Joystick.IGS, Switch Joystick.SLDASM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]
2022-05-17 Create wheel model.
2022-05-17 Add wheel model to base model.
2022-05-19 Add tech draw for wheel
2022-05-21 Create paddle shifter template.
    [Micro Switch with Lever closed.stp, Micro Switch with Lever open.stp, PaddleShifter.FCStd]
2022-05-22 Add paddle shifter link to wheel template.
    [Metalinis vairas.STEP, PaddleShifter.FCStd, vairas.STEP]
2022-05-23 Added model of fastening to the table
    [PaddleShifter.FCStd]
2022-07-06 Improved tech draw
    [00 - Pedalier CSP V2.SLDASM, 01 - Pied.SLDPRT, 02 - Pied SYM.SLDPRT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]
2022-07-06 Update tech draw.
    [Pedals.FCStd]
2022-07-19 Add HandBrake model.
    [HandBrake.FCStd, Pedals.FCStd]
2022-09-12 Create shifter model.
    [HandBrake.FCStd, Lower Plate.step, joy_stick_2a.step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]
